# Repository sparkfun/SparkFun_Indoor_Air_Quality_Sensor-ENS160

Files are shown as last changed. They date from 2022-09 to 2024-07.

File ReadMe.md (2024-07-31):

SparkFun Indoor Air Quality Sensor - ENS160
========================================

SparkFun Indoor Air Quality Sensor-ENS160 (https://www.sparkfun.com/products/20844)

[*SparkFun Indoor Air Quality Sensor-ENS160 (SEN-20844)*](https://www.sparkfun.com/products/20844)

The SparkFun ENS160 Indoor Air Quality Sensor is a digital multi-gas sensor solution with four sensor elements that can be used in a wide range of applications including building automation, smart home, and HVAC. The independent hotplate control allows the detection of volatile organic compounds (VOCs) including ethanol, toluene, hydrogen, and oxidizing gases with superior sensitivity. The ENS160 supports intelligent algorithms to process raw sensor measurements on-chip. These algorithms calculate CO2-equivalents, TVOC, air quality indices (AQIs), and perform humidity and temperature compensation, as well as baseline management, all on-chip. Raw sensor measurements can be read for further customization. 

The ENS160 from ScioSense is a digital multi-gas sensor consisting of four independent heaters and gas sensor elements based on metal oxide (MOX) technology and a controller. TrueVOC® air quality detection provides outputs such as eCO2, TVOC, and AQI in compliance with worldwide IAQ standards.

Along with the plug-and-play Qwiic connectors, both I<sup>2</sup>C and SPI functionality have been broken out to 0.1"-spaced pins in case you prefer to use a breadboard. 

**Note:** The default I<sup>2</sup>C address of the ENS160 is 0x53 and is jumper selectable to 0x52. 

Repository Contents
-------------------

* **/Documentation** - Data sheets, additional product information
* **/Hardware** - Eagle design files (.brd, .sch)
* **/Production** - Production panel files (.brd)

Documentation
--------------

* **[Fritzing Part](https://github.com/sparkfun/Fritzing_Parts/blob/main/products/20844_sfe_indoor_air_quality_sensor_ens160_qwiic_eco2_tvoc_aqi.fzpz)** - Fritzing part for the SparkFun Indoor Air Quality Sensor - ENS160.
* **[Library](https://github.com/sparkfun/SparkFun_Indoor_Air_Quality_Sensor-ENS160_Arduino_Library)** - Arduino library for the SparkFun Indoor Air Quality Sensor - ENS160.
* **[Hookup Guide](https://learn.sparkfun.com/tutorials/sparkfun-indoor-air-quality-sensor---ens160-qwiic-hookup-guide)** - Basic hookup guide for the SparkFun Indoor Air Quality Sensor - ENS160.

Product Versions
----------------
* [SEN-20844](https://www.sparkfun.com/products/20844) - v1.0

Version History
---------------
* v1.0 - Initial Release

License Information
-------------------

This product is _**open source**_! 

Please review the LICENSE.md file for license information. 

If you have any questions or concerns on licensing, please contact technical support on our [SparkFun forums](https://forum.sparkfun.com/viewforum.php?f=152).

Distributed as-is; no warranty is given.

- Your friends at SparkFun.

_<COLLABORATION CREDIT>_

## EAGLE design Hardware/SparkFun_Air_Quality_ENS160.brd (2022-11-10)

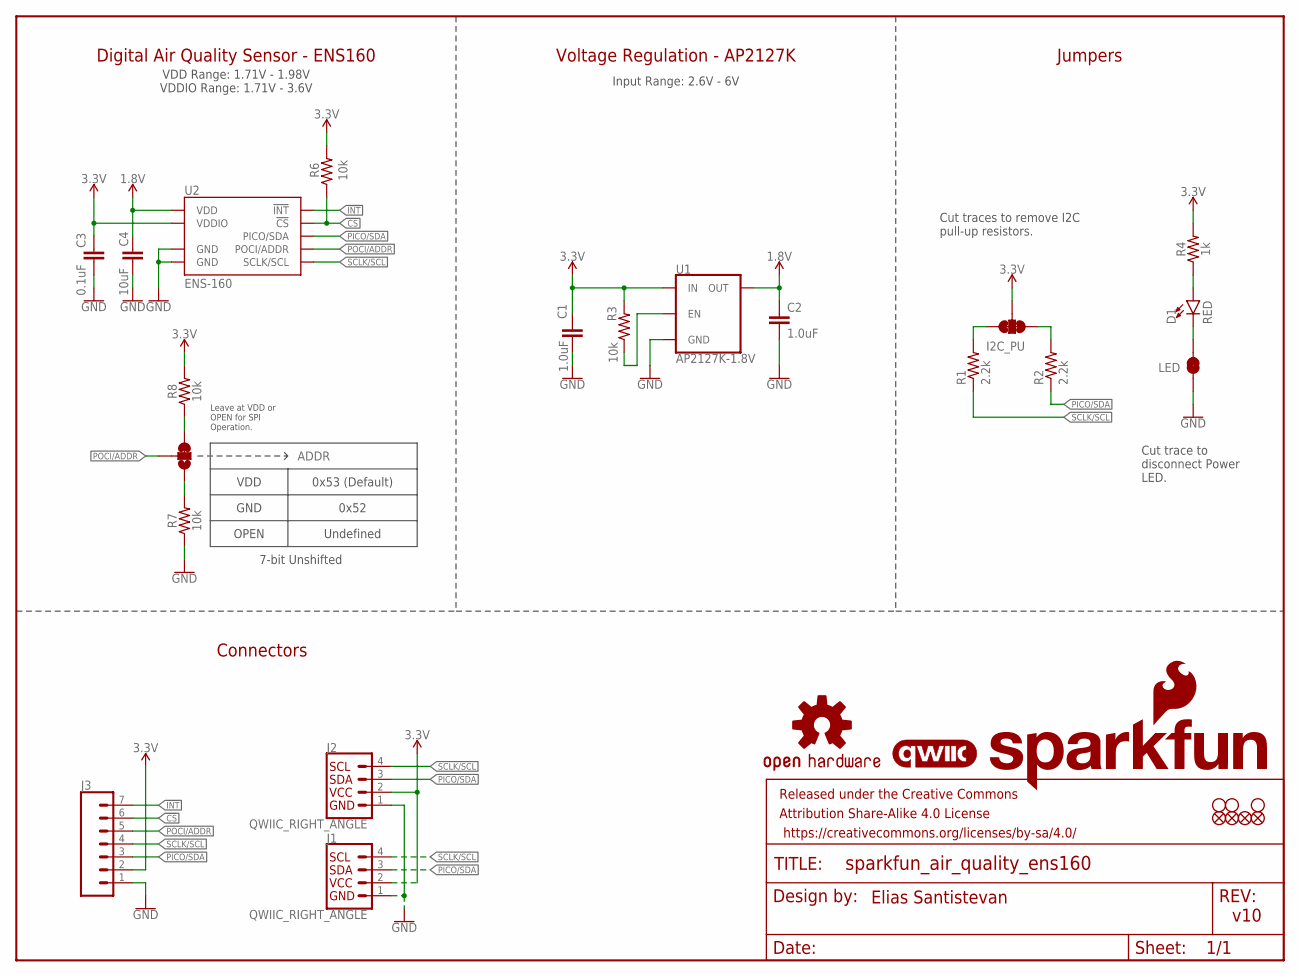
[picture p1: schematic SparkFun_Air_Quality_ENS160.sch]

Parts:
ADDR: JUMPER-SMT_3_1-NC_TRACE_SILK; SMT-JUMPER_3_1-NC_TRACE_SILK
C1, C2: 1.0uF; 0603
C3: 0.1uF; 0603
C4: 10uF; 0603
D1: RED; LED-0603
FD1, FD2, FD3, FD4: FIDUCIAL1X2; FIDUCIAL-1X2
FRAME1: FRAME-LETTER; CREATIVE_COMMONS
I2C_PU: S_MODE; SMT-JUMPER_3_2-NC_TRACE_SILK
J1, J2: QWIIC_RIGHT_ANGLE; JST04_1MM_RA
J3: CONN_07NO_SILK; 1X07_NO_SILK
LED: JUMPER-SMT_2_NC_TRACE_SILK; SMT-JUMPER_2_NC_TRACE_SILK
LOGO2: OSHW-LOGOMINI; OSHW-LOGO-MINI
LOGO3: SFE_LOGO_NAME_FLAME.1_INCH; SFE_LOGO_NAME_FLAME_.1
LOGO4: QWIIC_LOGO_4MM; QWIIC_4MM
R1, R2: 2.2k; 0603
R3, R6, R7, R8: 10k; 0603
R4: 1k; 0603
STANDOFF1, STANDOFF2, STANDOFF5: STAND-OFFTIGHT; STAND-OFF-TIGHT
U1: AP2127K-1.8V; SOT23-5
U2: ENS-160; LGA-9

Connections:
1.8V: C2.1, C4.1, U1.5 (OUT), U2.P4 (VDD)
3.3V: C1.1, C3.1, I2C_PU.2, J1.2, J2.2, J3.2, R3.2, R4.2, R6.2, R8.2, U1.1 (IN), U2.P5 (VDDIO)
!CS!: J3.6, R6.1, U2.P7 (!CS!)
!INT!: J3.7, U2.P6 (!INT!)
GND: C1.2, C2.2, C3.2, C4.2, J1.1, J2.1, J3.1, LED.1, R7.1, U1.2 (GND), U2.P8 (GND), U2.P9 (GND)
unnamed: R3.1, U1.3 (EN)
unnamed: D1.A, R4.1
unnamed: D1.C, LED.2
unnamed: ADDR.3, R8.1
unnamed: I2C_PU.1, R1.2
unnamed: I2C_PU.3, R2.2
unnamed: ADDR.1, R7.2
PICO/SDA: J1.3, J2.3, J3.3, R2.1, U2.P1 (PICO/SDA)
POCI/ADDR: ADDR.2, J3.5, U2.P3 (POCI/ADDR)
SCLK/SCL: J1.4, J2.4, J3.4, R1.1, U2.P2 (SCLK/SCL)

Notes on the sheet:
Cut traces to remove I2C pull-up resistors.
v10
Jumpers
Cut trace to disconnect Power LED.
Connectors
Elias Santistevan
Digital Air Quality Sensor - ENS160
VDD Range: 1.71V - 1.98V VDDIO Range: 1.71V - 3.6V
Voltage Regulation - AP2127K
VDD
GND
OPEN
0x52
0x53 (Default)
Undefined
7-bit Unshifted
Input Range: 2.6V - 6V
Leave at VDD or OPEN for SPI Operation.

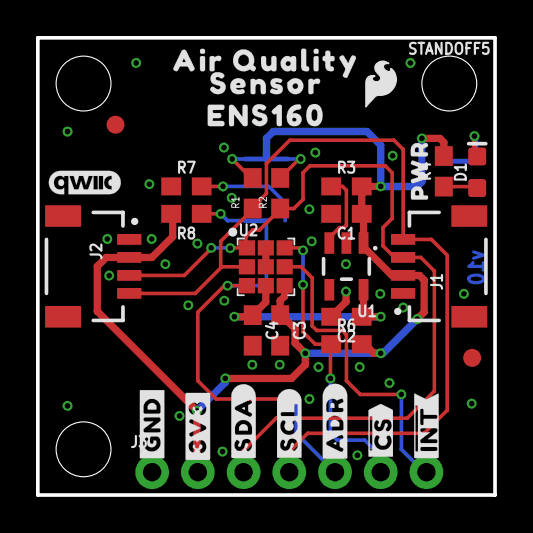
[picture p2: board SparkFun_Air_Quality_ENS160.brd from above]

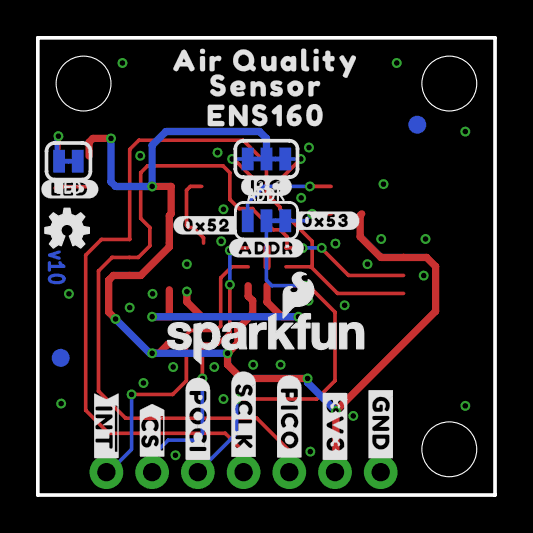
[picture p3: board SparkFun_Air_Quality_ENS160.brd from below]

Board: 2 copper layers, 25.4 x 25.4 mm, 58 parts (22 on the bottom side), 15 nets.

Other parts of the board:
U$1, U$9: #GND#3
U$2, U$10: #3V3#4
U$3: #SDA#5
U$4: #SCL#4
U$5, U$28: ENS16016
U$6: #ADDR#6
U$7: #SCLK#16021
U$8: #ADR#441018
U$11: ##INT##9
U$12, U$17: AIR_QUALITY441014
U$13, U$19: SENSOR441015
U$14: #0X53#16019
U$15: #0X52#16019
U$16: #LED#11
U$18: ##INT##6
U$20: SFE_LOGO_FLAME_.1
U$21: PWR9
U$22: ##CS##16019
U$23: #POCI#16020
U$24: #PICO#16021
U$25: #I2C#11
U$27: ##CS##441016

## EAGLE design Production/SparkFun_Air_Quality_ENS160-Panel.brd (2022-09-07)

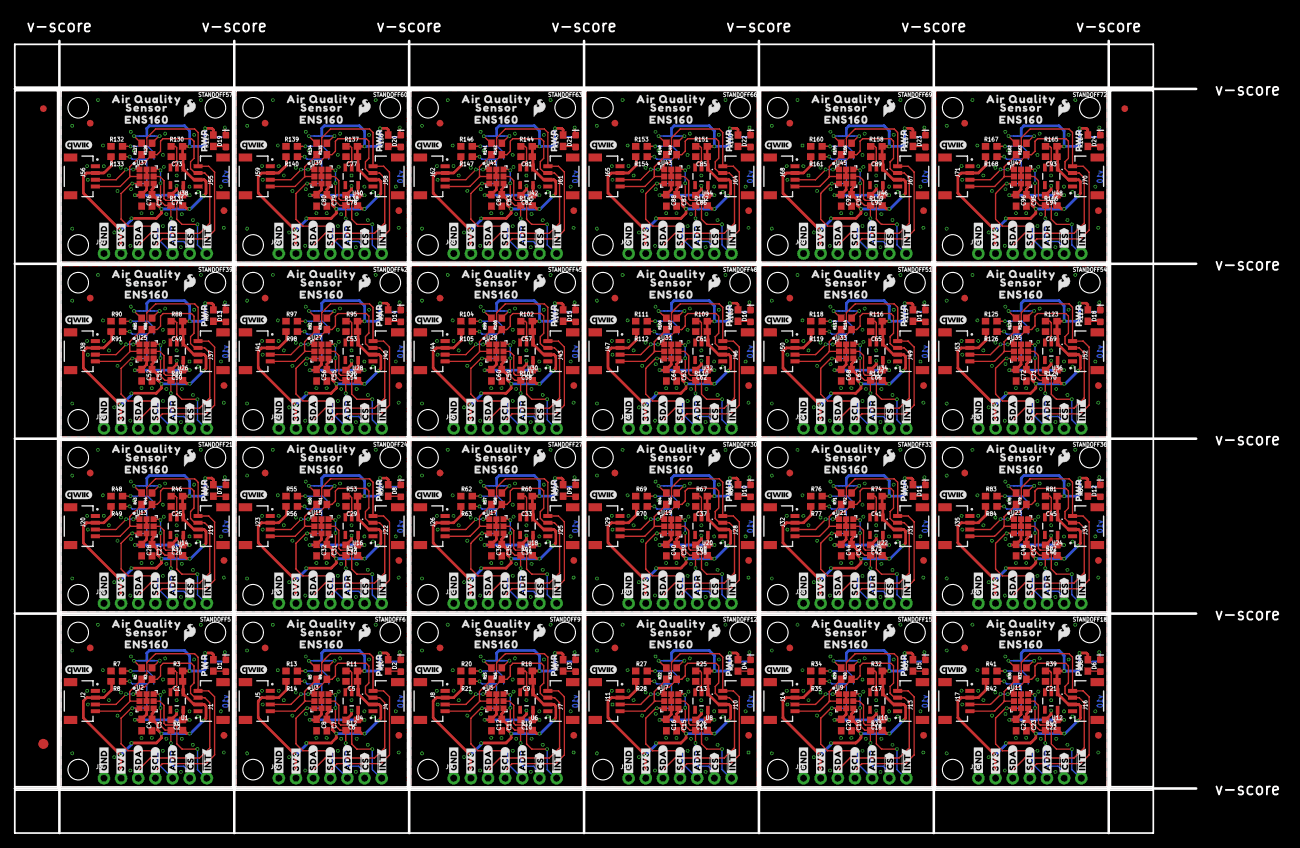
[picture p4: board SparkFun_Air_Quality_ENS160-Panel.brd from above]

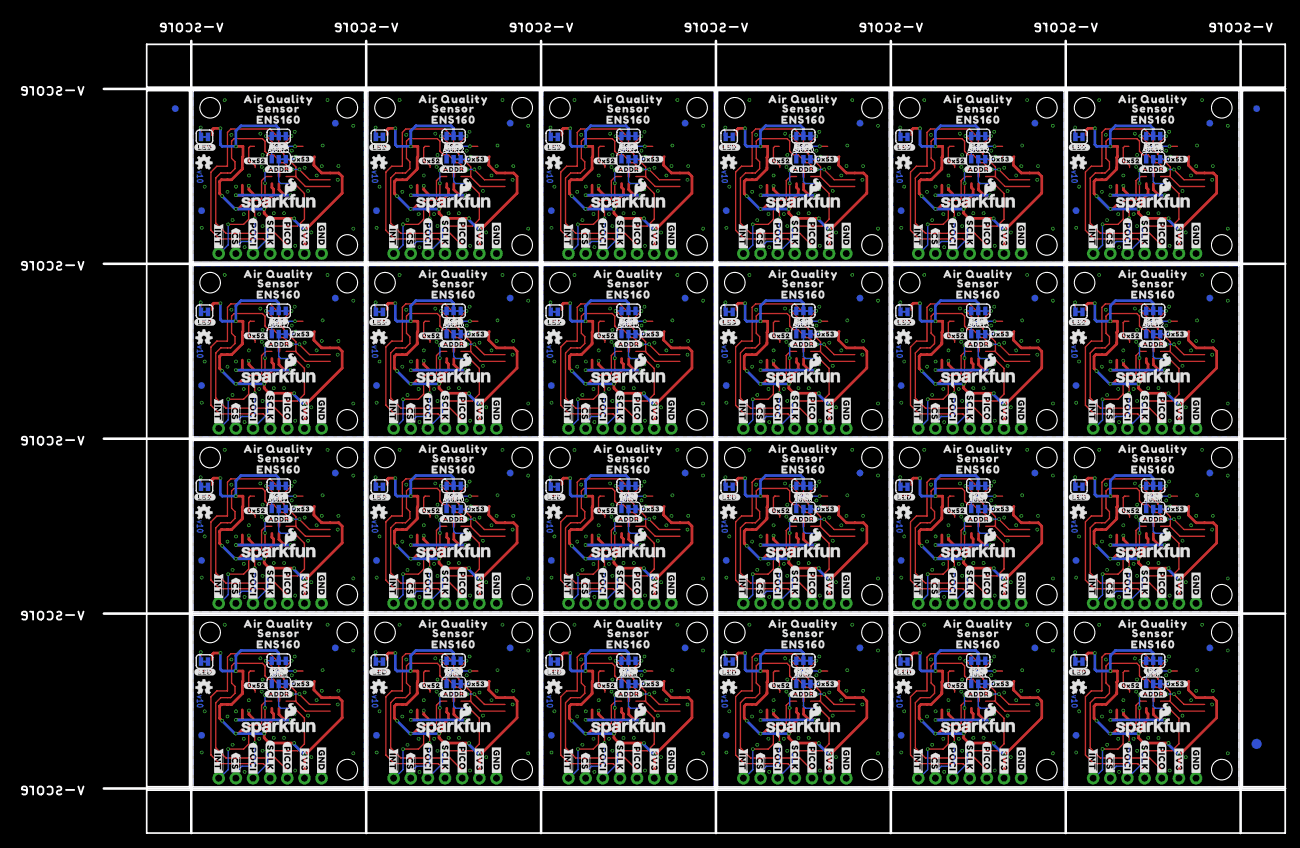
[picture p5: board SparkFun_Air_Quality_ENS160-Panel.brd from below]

Board: 2 copper layers, 175.0 x 117.3 mm, 1374 parts (531 on the bottom side), 360 nets.

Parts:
ADDR, ADDR1, ADDR2, ADDR3, ADDR4, ADDR5, ADDR6, ADDR7, ADDR8, ADDR9, ADDR10, ADDR11, ADDR12, ADDR13, ADDR14, ADDR15, ADDR16, ADDR17, ADDR18, ADDR19, ADDR20, ADDR21, ADDR22, ADDR23: JUMPER-SMT_3_1-NC_TRACE_SILK; SMT-JUMPER_3_1-NC_TRACE_SILK
C1, C2, C5, C6, C9, C10, C13, C14, C17, C18, C21, C22, C25, C26, C29, C30, C33, C34, C37, C38, C41, C42, C45, C46, C49, C50, C53, C54, C57, C58, C61, C62, C65, C66, C69, C70, C73, C74, C77, C78, C81, C82, C85, C86, C89, C90, C93, C94: 1.0uF; 0603
C3, C7, C11, C15, C19, C23, C27, C31, C35, C39, C43, C47, C51, C55, C59, C63, C67, C71, C75, C79, C83, C87, C91, C95: 0.1uF; 0603
C4, C8, C12, C16, C20, C24, C28, C32, C36, C40, C44, C48, C52, C56, C60, C64, C68, C72, C76, C80, C84, C88, C92, C96: 10uF; 0603
D1, D2, D3, D4, D5, D6, D7, D8, D9, D10, D11, D12, D13, D14, D15, D16, D17, D18, D19, D20, D21, D22, D23, D24: RED; LED-0603
E$1, E$2, E$3, E$4: FIDUCIAL-1X2
E$5, E$6: FIDUCIAL-1.5X3
FD1, FD2, FD3, FD4, FD5, FD6, FD7, FD8, FD9, FD10, FD11, FD12, FD13, FD14, FD15, FD16, FD17, FD18, FD19, FD20, FD21, FD22, FD23, FD24, FD25, FD26, FD27, FD28, FD29, FD30, FD31, FD32, FD33, FD34, FD35, FD36, FD37, FD38, FD39, FD40, FD41, FD42, FD43, FD44, FD45, FD46, FD47, FD48, FD49, FD50, FD51, FD52, FD53, FD54, FD55, FD56, FD57, FD58, FD59, FD60, FD61, FD62, FD63, FD64, FD65, FD66, FD67, FD68, FD69, FD70, FD71, FD72, FD73, FD74, FD75, FD76, FD77, FD78, FD79, FD80, FD81, FD82, FD83, FD84, FD85, FD86, FD87, FD88, FD89, FD90, FD91, FD92, FD93, FD94, FD95, FD96: FIDUCIAL1X2; FIDUCIAL-1X2
I2C_PU, I2C_PU1, I2C_PU2, I2C_PU3, I2C_PU4, I2C_PU5, I2C_PU6, I2C_PU7, I2C_PU8, I2C_PU9, I2C_PU10, I2C_PU11, I2C_PU12, I2C_PU13, I2C_PU14, I2C_PU15, I2C_PU16, I2C_PU17, I2C_PU18, I2C_PU19, I2C_PU20, I2C_PU21, I2C_PU22, I2C_PU23: S_MODE; SMT-JUMPER_3_2-NC_TRACE_SILK
J1, J2, J4, J5, J7, J8, J10, J11, J13, J14, J16, J17, J19, J20, J22, J23, J25, J26, J28, J29, J31, J32, J34, J35, J37, J38, J40, J41, J43, J44, J46, J47, J49, J50, J52, J53, J55, J56, J58, J59, J61, J62, J64, J65, J67, J68, J70, J71: QWIIC_RIGHT_ANGLE; JST04_1MM_RA
J3, J6, J9, J12, J15, J18, J21, J24, J27, J30, J33, J36, J39, J42, J45, J48, J51, J54, J57, J60, J63, J66, J69, J72: 1X07_NO_SILK
LED, LED1, LED2, LED3, LED4, LED5, LED6, LED7, LED8, LED9, LED10, LED11, LED12, LED13, LED14, LED15, LED16, LED17, LED18, LED19, LED20, LED21, LED22, LED23: JUMPER-SMT_2_NC_TRACE_SILK; SMT-JUMPER_2_NC_TRACE_SILK
LOGO1, LOGO2, LOGO7, LOGO10, LOGO13, LOGO16, LOGO19, LOGO22, LOGO25, LOGO28, LOGO31, LOGO34, LOGO37, LOGO40, LOGO43, LOGO46, LOGO49, LOGO52, LOGO55, LOGO58, LOGO61, LOGO64, LOGO67, LOGO70: OSHW-LOGOMINI; OSHW-LOGO-MINI
LOGO3, LOGO5, LOGO8, LOGO11, LOGO14, LOGO17, LOGO20, LOGO23, LOGO26, LOGO29, LOGO32, LOGO35, LOGO38, LOGO41, LOGO44, LOGO47, LOGO50, LOGO53, LOGO56, LOGO59, LOGO62, LOGO65, LOGO68, LOGO71: SFE_LOGO_NAME_FLAME.1_INCH; SFE_LOGO_NAME_FLAME_.1
LOGO4, LOGO6, LOGO9, LOGO12, LOGO15, LOGO18, LOGO21, LOGO24, LOGO27, LOGO30, LOGO33, LOGO36, LOGO39, LOGO42, LOGO45, LOGO48, LOGO51, LOGO54, LOGO57, LOGO60, LOGO63, LOGO66, LOGO69, LOGO72: QWIIC_LOGO_4MM; QWIIC_4MM
R1, R2, R5, R9, R15, R16, R22, R23, R29, R30, R36, R37, R43, R44, R50, R51, R57, R58, R64, R65, R71, R72, R78, R79, R85, R86, R92, R93, R99, R100, R106, R107, R113, R114, R120, R121, R127, R128, R134, R135, R141, R142, R148, R149, R155, R156, R162, R163: 2.2k; 0603
R3, R6, R7, R8, R11, R12, R13, R14, R18, R19, R20, R21, R25, R26, R27, R28, R32, R33, R34, R35, R39, R40, R41, R42, R46, R47, R48, R49, R53, R54, R55, R56, R60, R61, R62, R63, R67, R68, R69, R70, R74, R75, R76, R77, R81, R82, R83, R84, R88, R89, R90, R91, R95, R96, R97, R98, R102, R103, R104, R105, R109, R110, R111, R112, R116, R117, R118, R119, R123, R124, R125, R126, R130, R131, R132, R133, R137, R138, R139, R140, R144, R145, R146, R147, R151, R152, R153, R154, R158, R159, R160, R161, R165, R166, R167, R168: 10k; 0603
R4, R10, R17, R24, R31, R38, R45, R52, R59, R66, R73, R80, R87, R94, R101, R108, R115, R122, R129, R136, R143, R150, R157, R164: 1k; 0603
STANDOFF1, STANDOFF2, STANDOFF3, STANDOFF4, STANDOFF5, STANDOFF6, STANDOFF7, STANDOFF8, STANDOFF9, STANDOFF10, STANDOFF11, STANDOFF12, STANDOFF13, STANDOFF14, STANDOFF15, STANDOFF16, STANDOFF17, STANDOFF18, STANDOFF19, STANDOFF20, STANDOFF21, STANDOFF22, STANDOFF23, STANDOFF24, STANDOFF25, STANDOFF26, STANDOFF27, STANDOFF28, STANDOFF29, STANDOFF30, STANDOFF31, STANDOFF32, STANDOFF33, STANDOFF34, STANDOFF35, STANDOFF36, STANDOFF37, STANDOFF38, STANDOFF39, STANDOFF40, STANDOFF41, STANDOFF42, STANDOFF43, STANDOFF44, STANDOFF45, STANDOFF46, STANDOFF47, STANDOFF48, STANDOFF49, STANDOFF50, STANDOFF51, STANDOFF52, STANDOFF53, STANDOFF54, STANDOFF55, STANDOFF56, STANDOFF57, STANDOFF58, STANDOFF59, STANDOFF60, STANDOFF61, STANDOFF62, STANDOFF63, STANDOFF64, STANDOFF65, STANDOFF66, STANDOFF67, STANDOFF68, STANDOFF69, STANDOFF70, STANDOFF71, STANDOFF72: STAND-OFFTIGHT; STAND-OFF-TIGHT
U1, U4, U6, U8, U10, U12, U14, U16, U18, U20, U22, U24, U26, U28, U30, U32, U34, U36, U38, U40, U42, U44, U46, U48: AP2127K-1.8V; SOT23-5
U2, U3, U5, U7, U9, U11, U13, U15, U17, U19, U21, U23, U25, U27, U29, U31, U33, U35, U37, U39, U41, U43, U45, U47: ENS-160; LGA-9
U$1, U$9, U$30, U$34, U$57, U$61, U$84, U$88, U$111, U$115, U$138, U$142, U$165, U$169, U$192, U$196, U$219, U$223, U$246, U$250, U$273, U$277, U$300, U$304, U$327, U$331, U$354, U$358, U$381, U$385, U$408, U$412, U$435, U$439, U$462, U$466, U$489, U$493, U$516, U$520, U$543, U$547, U$570, U$574, U$597, U$601, U$624, U$628: #GND#3
U$2, U$10, U$31, U$35, U$58, U$62, U$85, U$89, U$112, U$116, U$139, U$143, U$166, U$170, U$193, U$197, U$220, U$224, U$247, U$251, U$274, U$278, U$301, U$305, U$328, U$332, U$355, U$359, U$382, U$386, U$409, U$413, U$436, U$440, U$463, U$467, U$490, U$494, U$517, U$521, U$544, U$548, U$571, U$575, U$598, U$602, U$625, U$629: #3V3#4
U$3, U$32, U$59, U$86, U$113, U$140, U$167, U$194, U$221, U$248, U$275, U$302, U$329, U$356, U$383, U$410, U$437, U$464, U$491, U$518, U$545, U$572, U$599, U$626: #SDA#5
U$4, U$33, U$60, U$87, U$114, U$141, U$168, U$195, U$222, U$249, U$276, U$303, U$330, U$357, U$384, U$411, U$438, U$465, U$492, U$519, U$546, U$573, U$600, U$627: #SCL#4
U$5, U$28, U$44, U$51, U$71, U$78, U$98, U$105, U$125, U$132, U$152, U$159, U$179, U$186, U$206, U$213, U$233, U$240, U$260, U$267, U$287, U$294, U$314, U$321, U$341, U$348, U$368, U$375, U$395, U$402, U$422, U$429, U$449, U$456, U$476, U$483, U$503, U$510, U$530, U$537, U$557, U$564, U$584, U$591, U$611, U$618, U$638, U$645: ENS16016
U$6, U$45, U$72, U$99, U$126, U$153, U$180, U$207, U$234, U$261, U$288, U$315, U$342, U$369, U$396, U$423, U$450, U$477, U$504, U$531, U$558, U$585, U$612, U$639: #ADDR#6
U$7, U$49, U$76, U$103, U$130, U$157, U$184, U$211, U$238, U$265, U$292, U$319, U$346, U$373, U$400, U$427, U$454, U$481, U$508, U$535, U$562, U$589, U$616, U$643: #SCLK#16021
U$8, U$52, U$79, U$106, U$133, U$160, U$187, U$214, U$241, U$268, U$295, U$322, U$349, U$376, U$403, U$430, U$457, U$484, U$511, U$538, U$565, U$592, U$619, U$646: #ADR#441018
U$11, U$37, U$64, U$91, U$118, U$145, U$172, U$199, U$226, U$253, U$280, U$307, U$334, U$361, U$388, U$415, U$442, U$469, U$496, U$523, U$550, U$577, U$604, U$631: ##INT##9
U$12, U$17, U$38, U$40, U$65, U$67, U$92, U$94, U$119, U$121, U$146, U$148, U$173, U$175, U$200, U$202, U$227, U$229, U$254, U$256, U$281, U$283, U$308, U$310, U$335, U$337, U$362, U$364, U$389, U$391, U$416, U$418, U$443, U$445, U$470, U$472, U$497, U$499, U$524, U$526, U$551, U$553, U$578, U$580, U$605, U$607, U$632, U$634: AIR_QUALITY441014
U$13, U$19, U$39, U$41, U$66, U$68, U$93, U$95, U$120, U$122, U$147, U$149, U$174, U$176, U$201, U$203, U$228, U$230, U$255, U$257, U$282, U$284, U$309, U$311, U$336, U$338, U$363, U$365, U$390, U$392, U$417, U$419, U$444, U$446, U$471, U$473, U$498, U$500, U$525, U$527, U$552, U$554, U$579, U$581, U$606, U$608, U$633, U$635: SENSOR441015
U$14, U$46, U$73, U$100, U$127, U$154, U$181, U$208, U$235, U$262, U$289, U$316, U$343, U$370, U$397, U$424, U$451, U$478, U$505, U$532, U$559, U$586, U$613, U$640: #0X53#16019
U$15, U$47, U$74, U$101, U$128, U$155, U$182, U$209, U$236, U$263, U$290, U$317, U$344, U$371, U$398, U$425, U$452, U$479, U$506, U$533, U$560, U$587, U$614, U$641: #0X52#16019
U$16, U$26, U$55, U$82, U$109, U$136, U$163, U$190, U$217, U$244, U$271, U$298, U$325, U$352, U$379, U$406, U$433, U$460, U$487, U$514, U$541, U$568, U$595, U$622: #LED#11
U$18, U$36, U$63, U$90, U$117, U$144, U$171, U$198, U$225, U$252, U$279, U$306, U$333, U$360, U$387, U$414, U$441, U$468, U$495, U$522, U$549, U$576, U$603, U$630: ##INT##6
U$20, U$42, U$69, U$96, U$123, U$150, U$177, U$204, U$231, U$258, U$285, U$312, U$339, U$366, U$393, U$420, U$447, U$474, U$501, U$528, U$555, U$582, U$609, U$636: SFE_LOGO_FLAME_.1
U$21, U$43, U$70, U$97, U$124, U$151, U$178, U$205, U$232, U$259, U$286, U$313, U$340, U$367, U$394, U$421, U$448, U$475, U$502, U$529, U$556, U$583, U$610, U$637: PWR9
U$22, U$48, U$75, U$102, U$129, U$156, U$183, U$210, U$237, U$264, U$291, U$318, U$345, U$372, U$399, U$426, U$453, U$480, U$507, U$534, U$561, U$588, U$615, U$642: ##CS##16019
U$23, U$53, U$80, U$107, U$134, U$161, U$188, U$215, U$242, U$269, U$296, U$323, U$350, U$377, U$404, U$431, U$458, U$485, U$512, U$539, U$566, U$593, U$620, U$647: #POCI#16020
U$24, U$54, U$81, U$108, U$135, U$162, U$189, U$216, U$243, U$270, U$297, U$324, U$351, U$378, U$405, U$432, U$459, U$486, U$513, U$540, U$567, U$594, U$621, U$648: #PICO#16021
U$25, U$29, U$56, U$83, U$110, U$137, U$164, U$191, U$218, U$245, U$272, U$299, U$326, U$353, U$380, U$407, U$434, U$461, U$488, U$515, U$542, U$569, U$596, U$623: #I2C#11
U$27, U$50, U$77, U$104, U$131, U$158, U$185, U$212, U$239, U$266, U$293, U$320, U$347, U$374, U$401, U$428, U$455, U$482, U$509, U$536, U$563, U$590, U$617, U$644: ##CS##441016

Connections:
1.8V: C2.1, C4.1, U1.5, U2.P4
1.8V1: C6.1, C8.1, U3.P4, U4.5
1.8V2: C10.1, C12.1, U5.P4, U6.5
1.8V3: C14.1, C16.1, U7.P4, U8.5
1.8V4: C18.1, C20.1, U9.P4, U10.5
1.8V5: C22.1, C24.1, U11.P4, U12.5
1.8V6: C26.1, C28.1, U13.P4, U14.5
1.8V7: C30.1, C32.1, U15.P4, U16.5
1.8V8: C34.1, C36.1, U17.P4, U18.5
1.8V9: C38.1, C40.1, U19.P4, U20.5
1.8V10: C42.1, C44.1, U21.P4, U22.5
1.8V11: C46.1, C48.1, U23.P4, U24.5
1.8V12: C50.1, C52.1, U25.P4, U26.5
1.8V13: C54.1, C56.1, U27.P4, U28.5
1.8V14: C58.1, C60.1, U29.P4, U30.5
1.8V15: C62.1, C64.1, U31.P4, U32.5
1.8V16: C66.1, C68.1, U33.P4, U34.5
1.8V17: C70.1, C72.1, U35.P4, U36.5
1.8V18: C74.1, C76.1, U37.P4, U38.5
1.8V19: C78.1, C80.1, U39.P4, U40.5
1.8V20: C82.1, C84.1, U41.P4, U42.5
1.8V21: C86.1, C88.1, U43.P4, U44.5
1.8V22: C90.1, C92.1, U45.P4, U46.5
1.8V23: C94.1, C96.1, U47.P4, U48.5
3.3V: C1.1, C3.1, I2C_PU.2, J1.2, J2.2, J3.2, R3.2, R4.2, R6.2, R8.2, U1.1, U2.P5
3.3V1: C5.1, C7.1, I2C_PU1.2, J4.2, J5.2, J6.2, R10.2, R11.2, R12.2, R14.2, U3.P5, U4.1
3.3V2: C9.1, C11.1, I2C_PU2.2, J7.2, J8.2, J9.2, R17.2, R18.2, R19.2, R21.2, U5.P5, U6.1
3.3V3: C13.1, C15.1, I2C_PU3.2, J10.2, J11.2, J12.2, R24.2, R25.2, R26.2, R28.2, U7.P5, U8.1
3.3V4: C17.1, C19.1, I2C_PU4.2, J13.2, J14.2, J15.2, R31.2, R32.2, R33.2, R35.2, U9.P5, U10.1
3.3V5: C21.1, C23.1, I2C_PU5.2, J16.2, J17.2, J18.2, R38.2, R39.2, R40.2, R42.2, U11.P5, U12.1
3.3V6: C25.1, C27.1, I2C_PU6.2, J19.2, J20.2, J21.2, R45.2, R46.2, R47.2, R49.2, U13.P5, U14.1
3.3V7: C29.1, C31.1, I2C_PU7.2, J22.2, J23.2, J24.2, R52.2, R53.2, R54.2, R56.2, U15.P5, U16.1
3.3V8: C33.1, C35.1, I2C_PU8.2, J25.2, J26.2, J27.2, R59.2, R60.2, R61.2, R63.2, U17.P5, U18.1
3.3V9: C37.1, C39.1, I2C_PU9.2, J28.2, J29.2, J30.2, R66.2, R67.2, R68.2, R70.2, U19.P5, U20.1
3.3V10: C41.1, C43.1, I2C_PU10.2, J31.2, J32.2, J33.2, R73.2, R74.2, R75.2, R77.2, U21.P5, U22.1
3.3V11: C45.1, C47.1, I2C_PU11.2, J34.2, J35.2, J36.2, R80.2, R81.2, R82.2, R84.2, U23.P5, U24.1
3.3V12: C49.1, C51.1, I2C_PU12.2, J37.2, J38.2, J39.2, R87.2, R88.2, R89.2, R91.2, U25.P5, U26.1
3.3V13: C53.1, C55.1, I2C_PU13.2, J40.2, J41.2, J42.2, R94.2, R95.2, R96.2, R98.2, U27.P5, U28.1
3.3V14: C57.1, C59.1, I2C_PU14.2, J43.2, J44.2, J45.2, R101.2, R102.2, R103.2, R105.2, U29.P5, U30.1
3.3V15: C61.1, C63.1, I2C_PU15.2, J46.2, J47.2, J48.2, R108.2, R109.2, R110.2, R112.2, U31.P5, U32.1
3.3V16: C65.1, C67.1, I2C_PU16.2, J49.2, J50.2, J51.2, R115.2, R116.2, R117.2, R119.2, U33.P5, U34.1
3.3V17: C69.1, C71.1, I2C_PU17.2, J52.2, J53.2, J54.2, R122.2, R123.2, R124.2, R126.2, U35.P5, U36.1
3.3V18: C73.1, C75.1, I2C_PU18.2, J55.2, J56.2, J57.2, R129.2, R130.2, R131.2, R133.2, U37.P5, U38.1
3.3V19: C77.1, C79.1, I2C_PU19.2, J58.2, J59.2, J60.2, R136.2, R137.2, R138.2, R140.2, U39.P5, U40.1
3.3V20: C81.1, C83.1, I2C_PU20.2, J61.2, J62.2, J63.2, R143.2, R144.2, R145.2, R147.2, U41.P5, U42.1
3.3V21: C85.1, C87.1, I2C_PU21.2, J64.2, J65.2, J66.2, R150.2, R151.2, R152.2, R154.2, U43.P5, U44.1
3.3V22: C89.1, C91.1, I2C_PU22.2, J67.2, J68.2, J69.2, R157.2, R158.2, R159.2, R161.2, U45.P5, U46.1
3.3V23: C93.1, C95.1, I2C_PU23.2, J70.2, J71.2, J72.2, R164.2, R165.2, R166.2, R168.2, U47.P5, U48.1
!CS!: J3.6, R6.1, U2.P7
!CS!1: J6.6, R12.1, U3.P7
!CS!2: J9.6, R19.1, U5.P7
!CS!3: J12.6, R26.1, U7.P7
!CS!4: J15.6, R33.1, U9.P7
!CS!5: J18.6, R40.1, U11.P7
!CS!6: J21.6, R47.1, U13.P7
!CS!7: J24.6, R54.1, U15.P7
!CS!8: J27.6, R61.1, U17.P7
!CS!9: J30.6, R68.1, U19.P7
!CS!10: J33.6, R75.1, U21.P7
!CS!11: J36.6, R82.1, U23.P7
!CS!12: J39.6, R89.1, U25.P7
!CS!13: J42.6, R96.1, U27.P7
!CS!14: J45.6, R103.1, U29.P7
!CS!15: J48.6, R110.1, U31.P7
!CS!16: J51.6, R117.1, U33.P7
!CS!17: J54.6, R124.1, U35.P7
!CS!18: J57.6, R131.1, U37.P7
!CS!19: J60.6, R138.1, U39.P7
!CS!20: J63.6, R145.1, U41.P7
!CS!21: J66.6, R152.1, U43.P7
!CS!22: J69.6, R159.1, U45.P7
!CS!23: J72.6, R166.1, U47.P7
!INT!: J3.7, U2.P6
!INT!1: J6.7, U3.P6
!INT!2: J9.7, U5.P6
!INT!3: J12.7, U7.P6
!INT!4: J15.7, U9.P6
!INT!5: J18.7, U11.P6
!INT!6: J21.7, U13.P6
!INT!7: J24.7, U15.P6
!INT!8: J27.7, U17.P6
!INT!9: J30.7, U19.P6
!INT!10: J33.7, U21.P6
!INT!11: J36.7, U23.P6
!INT!12: J39.7, U25.P6
!INT!13: J42.7, U27.P6
!INT!14: J45.7, U29.P6
!INT!15: J48.7, U31.P6
!INT!16: J51.7, U33.P6
!INT!17: J54.7, U35.P6
!INT!18: J57.7, U37.P6
!INT!19: J60.7, U39.P6
!INT!20: J63.7, U41.P6
!INT!21: J66.7, U43.P6
!INT!22: J69.7, U45.P6
!INT!23: J72.7, U47.P6
GND: C1.2, C2.2, C3.2, C4.2, J1.1, J2.1, J3.1, LED.1, R7.1, U1.2, U2.P8, U2.P9
GND1: C5.2, C6.2, C7.2, C8.2, J4.1, J5.1, J6.1, LED1.1, R13.1, U3.P8, U3.P9, U4.2
GND2: C9.2, C10.2, C11.2, C12.2, J7.1, J8.1, J9.1, LED2.1, R20.1, U5.P8, U5.P9, U6.2
GND3: C13.2, C14.2, C15.2, C16.2, J10.1, J11.1, J12.1, LED3.1, R27.1, U7.P8, U7.P9, U8.2
GND4: C17.2, C18.2, C19.2, C20.2, J13.1, J14.1, J15.1, LED4.1, R34.1, U9.P8, U9.P9, U10.2
GND5: C21.2, C22.2, C23.2, C24.2, J16.1, J17.1, J18.1, LED5.1, R41.1, U11.P8, U11.P9, U12.2
GND6: C25.2, C26.2, C27.2, C28.2, J19.1, J20.1, J21.1, LED6.1, R48.1, U13.P8, U13.P9, U14.2
GND7: C29.2, C30.2, C31.2, C32.2, J22.1, J23.1, J24.1, LED7.1, R55.1, U15.P8, U15.P9, U16.2
GND8: C33.2, C34.2, C35.2, C36.2, J25.1, J26.1, J27.1, LED8.1, R62.1, U17.P8, U17.P9, U18.2
GND9: C37.2, C38.2, C39.2, C40.2, J28.1, J29.1, J30.1, LED9.1, R69.1, U19.P8, U19.P9, U20.2
GND10: C41.2, C42.2, C43.2, C44.2, J31.1, J32.1, J33.1, LED10.1, R76.1, U21.P8, U21.P9, U22.2
GND11: C45.2, C46.2, C47.2, C48.2, J34.1, J35.1, J36.1, LED11.1, R83.1, U23.P8, U23.P9, U24.2
GND12: C49.2, C50.2, C51.2, C52.2, J37.1, J38.1, J39.1, LED12.1, R90.1, U25.P8, U25.P9, U26.2
GND13: C53.2, C54.2, C55.2, C56.2, J40.1, J41.1, J42.1, LED13.1, R97.1, U27.P8, U27.P9, U28.2
GND14: C57.2, C58.2, C59.2, C60.2, J43.1, J44.1, J45.1, LED14.1, R104.1, U29.P8, U29.P9, U30.2
GND15: C61.2, C62.2, C63.2, C64.2, J46.1, J47.1, J48.1, LED15.1, R111.1, U31.P8, U31.P9, U32.2
GND16: C65.2, C66.2, C67.2, C68.2, J49.1, J50.1, J51.1, LED16.1, R118.1, U33.P8, U33.P9, U34.2
GND17: C69.2, C70.2, C71.2, C72.2, J52.1, J53.1, J54.1, LED17.1, R125.1, U35.P8, U35.P9, U36.2
GND18: C73.2, C74.2, C75.2, C76.2, J55.1, J56.1, J57.1, LED18.1, R132.1, U37.P8, U37.P9, U38.2
GND19: C77.2, C78.2, C79.2, C80.2, J58.1, J59.1, J60.1, LED19.1, R139.1, U39.P8, U39.P9, U40.2
GND20: C81.2, C82.2, C83.2, C84.2, J61.1, J62.1, J63.1, LED20.1, R146.1, U41.P8, U41.P9, U42.2
GND21: C85.2, C86.2, C87.2, C88.2, J64.1, J65.1, J66.1, LED21.1, R153.1, U43.P8, U43.P9, U44.2
GND22: C89.2, C90.2, C91.2, C92.2, J67.1, J68.1, J69.1, LED22.1, R160.1, U45.P8, U45.P9, U46.2
GND23: C93.2, C94.2, C95.2, C96.2, J70.1, J71.1, J72.1, LED23.1, R167.1, U47.P8, U47.P9, U48.2
unnamed: R3.1, U1.3
unnamed: D1.A, R4.1
unnamed: D1.C, LED.2
unnamed: ADDR.3, R8.1
unnamed: I2C_PU.1, R1.2
unnamed: I2C_PU.3, R2.2
unnamed: ADDR.1, R7.2
unnamed: I2C_PU1.1, R5.2
unnamed: I2C_PU1.3, R9.2
unnamed: D2.A, R10.1
unnamed: D2.C, LED1.2
unnamed: R11.1, U4.3
unnamed: ADDR1.3, R14.1
unnamed: ADDR1.1, R13.2
unnamed: I2C_PU2.1, R15.2
unnamed: I2C_PU2.3, R16.2
unnamed: D3.A, R17.1
unnamed: D3.C, LED2.2
unnamed: R18.1, U6.3
unnamed: ADDR2.3, R21.1
unnamed: ADDR2.1, R20.2
unnamed: I2C_PU3.1, R22.2
unnamed: I2C_PU3.3, R23.2
unnamed: D4.A, R24.1
unnamed: D4.C, LED3.2
unnamed: R25.1, U8.3
unnamed: ADDR3.3, R28.1
unnamed: ADDR3.1, R27.2
unnamed: I2C_PU4.1, R29.2
unnamed: I2C_PU4.3, R30.2
unnamed: D5.A, R31.1
unnamed: D5.C, LED4.2
unnamed: R32.1, U10.3
unnamed: ADDR4.3, R35.1
unnamed: ADDR4.1, R34.2
unnamed: I2C_PU5.1, R36.2
unnamed: I2C_PU5.3, R37.2
unnamed: D6.A, R38.1
unnamed: D6.C, LED5.2
unnamed: R39.1, U12.3
unnamed: ADDR5.3, R42.1
unnamed: ADDR5.1, R41.2
unnamed: I2C_PU6.1, R43.2
unnamed: I2C_PU6.3, R44.2
unnamed: D7.A, R45.1
unnamed: D7.C, LED6.2
unnamed: R46.1, U14.3
unnamed: ADDR6.3, R49.1
unnamed: ADDR6.1, R48.2
unnamed: I2C_PU7.1, R50.2
unnamed: I2C_PU7.3, R51.2
unnamed: D8.A, R52.1
unnamed: D8.C, LED7.2
unnamed: R53.1, U16.3
unnamed: ADDR7.3, R56.1
unnamed: ADDR7.1, R55.2
unnamed: I2C_PU8.1, R57.2
unnamed: I2C_PU8.3, R58.2
unnamed: D9.A, R59.1
unnamed: D9.C, LED8.2
unnamed: R60.1, U18.3
unnamed: ADDR8.3, R63.1
unnamed: ADDR8.1, R62.2
unnamed: I2C_PU9.1, R64.2
unnamed: I2C_PU9.3, R65.2
unnamed: D10.A, R66.1
unnamed: D10.C, LED9.2
unnamed: R67.1, U20.3
unnamed: ADDR9.3, R70.1
unnamed: ADDR9.1, R69.2
unnamed: I2C_PU10.1, R71.2
unnamed: I2C_PU10.3, R72.2
unnamed: D11.A, R73.1
unnamed: D11.C, LED10.2
unnamed: R74.1, U22.3
unnamed: ADDR10.3, R77.1
unnamed: ADDR10.1, R76.2
unnamed: I2C_PU11.1, R78.2
unnamed: I2C_PU11.3, R79.2
unnamed: D12.A, R80.1
unnamed: D12.C, LED11.2
unnamed: R81.1, U24.3
unnamed: ADDR11.3, R84.1
unnamed: ADDR11.1, R83.2
unnamed: I2C_PU12.1, R85.2
unnamed: I2C_PU12.3, R86.2
unnamed: D13.A, R87.1
unnamed: D13.C, LED12.2
unnamed: R88.1, U26.3
unnamed: ADDR12.3, R91.1
unnamed: ADDR12.1, R90.2
unnamed: I2C_PU13.1, R92.2
unnamed: I2C_PU13.3, R93.2
unnamed: D14.A, R94.1
unnamed: D14.C, LED13.2
unnamed: R95.1, U28.3
unnamed: ADDR13.3, R98.1
unnamed: ADDR13.1, R97.2
unnamed: I2C_PU14.1, R99.2
unnamed: I2C_PU14.3, R100.2
unnamed: D15.A, R101.1
unnamed: D15.C, LED14.2
unnamed: R102.1, U30.3
unnamed: ADDR14.3, R105.1
unnamed: ADDR14.1, R104.2
unnamed: I2C_PU15.1, R106.2
unnamed: I2C_PU15.3, R107.2
unnamed: D16.A, R108.1
unnamed: D16.C, LED15.2
unnamed: R109.1, U32.3
unnamed: ADDR15.3, R112.1
unnamed: ADDR15.1, R111.2
unnamed: I2C_PU16.1, R113.2
unnamed: I2C_PU16.3, R114.2
unnamed: D17.A, R115.1
unnamed: D17.C, LED16.2
unnamed: R116.1, U34.3
unnamed: ADDR16.3, R119.1
unnamed: ADDR16.1, R118.2
unnamed: I2C_PU17.1, R120.2
unnamed: I2C_PU17.3, R121.2
unnamed: D18.A, R122.1
unnamed: D18.C, LED17.2
unnamed: R123.1, U36.3
unnamed: ADDR17.3, R126.1
unnamed: ADDR17.1, R125.2
unnamed: I2C_PU18.1, R127.2
unnamed: I2C_PU18.3, R128.2
unnamed: D19.A, R129.1
unnamed: D19.C, LED18.2
unnamed: R130.1, U38.3
unnamed: ADDR18.3, R133.1
unnamed: ADDR18.1, R132.2
unnamed: I2C_PU19.1, R134.2
unnamed: I2C_PU19.3, R135.2
unnamed: D20.A, R136.1
unnamed: D20.C, LED19.2
unnamed: R137.1, U40.3
unnamed: ADDR19.3, R140.1
unnamed: ADDR19.1, R139.2
unnamed: I2C_PU20.1, R141.2
unnamed: I2C_PU20.3, R142.2
unnamed: D21.A, R143.1
unnamed: D21.C, LED20.2
unnamed: R144.1, U42.3
unnamed: ADDR20.3, R147.1
unnamed: ADDR20.1, R146.2
unnamed: I2C_PU21.1, R148.2
unnamed: I2C_PU21.3, R149.2
unnamed: D22.A, R150.1
unnamed: D22.C, LED21.2
unnamed: R151.1, U44.3
unnamed: ADDR21.3, R154.1
unnamed: ADDR21.1, R153.2
unnamed: I2C_PU22.1, R155.2
unnamed: I2C_PU22.3, R156.2
unnamed: D23.A, R157.1
unnamed: D23.C, LED22.2
unnamed: R158.1, U46.3
unnamed: ADDR22.3, R161.1
unnamed: ADDR22.1, R160.2
unnamed: I2C_PU23.1, R162.2
unnamed: I2C_PU23.3, R163.2
unnamed: D24.A, R164.1
unnamed: D24.C, LED23.2
unnamed: R165.1, U48.3
unnamed: ADDR23.3, R168.1
unnamed: ADDR23.1, R167.2
PICO/SDA: J1.3, J2.3, J3.3, R2.1, U2.P1
PICO/SDA1: J4.3, J5.3, J6.3, R9.1, U3.P1
PICO/SDA2: J7.3, J8.3, J9.3, R16.1, U5.P1
PICO/SDA3: J10.3, J11.3, J12.3, R23.1, U7.P1
PICO/SDA4: J13.3, J14.3, J15.3, R30.1, U9.P1
PICO/SDA5: J16.3, J17.3, J18.3, R37.1, U11.P1
PICO/SDA6: J19.3, J20.3, J21.3, R44.1, U13.P1
PICO/SDA7: J22.3, J23.3, J24.3, R51.1, U15.P1
PICO/SDA8: J25.3, J26.3, J27.3, R58.1, U17.P1
PICO/SDA9: J28.3, J29.3, J30.3, R65.1, U19.P1
PICO/SDA10: J31.3, J32.3, J33.3, R72.1, U21.P1
PICO/SDA11: J34.3, J35.3, J36.3, R79.1, U23.P1
PICO/SDA12: J37.3, J38.3, J39.3, R86.1, U25.P1
PICO/SDA13: J40.3, J41.3, J42.3, R93.1, U27.P1
PICO/SDA14: J43.3, J44.3, J45.3, R100.1, U29.P1
PICO/SDA15: J46.3, J47.3, J48.3, R107.1, U31.P1
PICO/SDA16: J49.3, J50.3, J51.3, R114.1, U33.P1
PICO/SDA17: J52.3, J53.3, J54.3, R121.1, U35.P1
PICO/SDA18: J55.3, J56.3, J57.3, R128.1, U37.P1
PICO/SDA19: J58.3, J59.3, J60.3, R135.1, U39.P1
PICO/SDA20: J61.3, J62.3, J63.3, R142.1, U41.P1
PICO/SDA21: J64.3, J65.3, J66.3, R149.1, U43.P1
PICO/SDA22: J67.3, J68.3, J69.3, R156.1, U45.P1
PICO/SDA23: J70.3, J71.3, J72.3, R163.1, U47.P1
POCI/ADDR: ADDR.2, J3.5, U2.P3
POCI/ADDR1: ADDR1.2, J6.5, U3.P3
POCI/ADDR2: ADDR2.2, J9.5, U5.P3
POCI/ADDR3: ADDR3.2, J12.5, U7.P3
POCI/ADDR4: ADDR4.2, J15.5, U9.P3
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

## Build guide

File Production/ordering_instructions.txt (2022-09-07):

panel size, 169x117mm
PCB thickness, 1.6mm
number of layers, 2
soldermask color, Red
silkscreen color, White
oz copper, 1oz
finish, HASL lead free
stencils, top
pcs per panel, 24
min trace width, 0.2032mm / 0.0080in
min drill size, 0.3048mm / 0.0120in

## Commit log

2022-09-02 Initial Commit - roughly routed Qwiic board
    [SparkFun_Air_Quality_ENS160_Qwiic_Micro.brd, SparkFun_Air_Quality_ENS160_Qwiic_Micro.sch]
2022-09-02 Commits the Qwiic Board (what the last commit tried to do)
    [SparkFun_Air_Quality_ENS160.brd, SparkFun_Air_Quality_ENS160.sch]
2022-09-02 Removes Qwiic Micro and extraneous libs
    [SparkFun_Air_Quality_ENS160_Qwiic_Micro.brd, SparkFun_Air_Quality_ENS160_Qwiic_Micro.sch]
2022-09-02 Finishes routing, adds silk
    * Updates ENS160 symbol to be smaller
    * Adds "U" prefix to device
    [SparkFun_Air_Quality_ENS160.brd, SparkFun_Air_Quality_ENS160.sch]
2022-09-06 Fixes ENS160 symbol to use the correct SPI terminology
    * Fixes net names that also used the wrong SPI terminology
    * Puts pin one symbol on the correct layer for the ENS160
    * Generally fixes ground pour in a number of areas
    * Changes version number in schematic
    [SparkFun_Air_Quality_ENS160.brd, SparkFun_Air_Quality_ENS160.sch]
2022-09-06 Updates board to reflect changes in pin numbers
    [SparkFun_Air_Quality_ENS160.brd, SparkFun_Air_Quality_ENS160.sch]
2022-09-06 Updated decoupling cap on VDD
    * Updates silk
    [SparkFun_Air_Quality_ENS160.brd, SparkFun_Air_Quality_ENS160.sch]
2022-09-06 Fixes changes to ENS160
    * In a panic I swapped pins rather than change the names on the pins - this has been undone. As a result I went to a previous version of the board and fixed the minor problems previously fixed:
    * Fixes general ground pour problems
    * Fixes silk
    * Adds ADR to top pin
    * Rolls version back to v10
    * Changes VDD decoupling cap to 10uF - not 0.1uF
    [SparkFun_Air_Quality_ENS160.brd, SparkFun_Air_Quality_ENS160.sch]
2022-09-07 Changes all values to 10k, removes pull up on interrupt
    [SparkFun_Air_Quality_ENS160.brd, SparkFun_Air_Quality_ENS160.sch]
2022-09-07 Changes enable pin pullup to 10k on the VREG
    [SparkFun_Air_Quality_ENS160.brd, SparkFun_Air_Quality_ENS160.sch]
2022-09-07 Removes "Qwiic" folder, adds Production files
    [SparkFun_Air_Quality_ENS160-Panel.GBL, SparkFun_Air_Quality_ENS160-Panel.GBP, SparkFun_Air_Quality_ENS160-Panel.GBS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]
2022-10-25 Fixes address selection notes
    [SparkFun_Air_Quality_ENS160.sch]
2022-10-28 Updates ENS symbol
    [SparkFun_Air_Quality_ENS160.sch]
2022-11-10 Removes unused library - new sensor added so SparkFun library
    [SparkFun_Air_Quality_ENS160.brd, SparkFun_Air_Quality_ENS160.sch]

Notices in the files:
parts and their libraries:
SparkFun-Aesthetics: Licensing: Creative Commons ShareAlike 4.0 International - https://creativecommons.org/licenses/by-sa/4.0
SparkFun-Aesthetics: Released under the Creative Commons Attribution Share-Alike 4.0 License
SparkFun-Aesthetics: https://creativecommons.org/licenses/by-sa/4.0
